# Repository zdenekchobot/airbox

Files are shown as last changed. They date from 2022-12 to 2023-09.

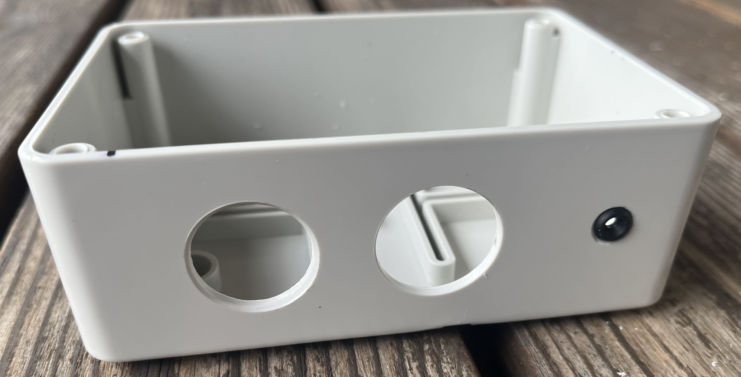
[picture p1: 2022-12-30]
Obrázky/Vyvrtaná krabička.jpg

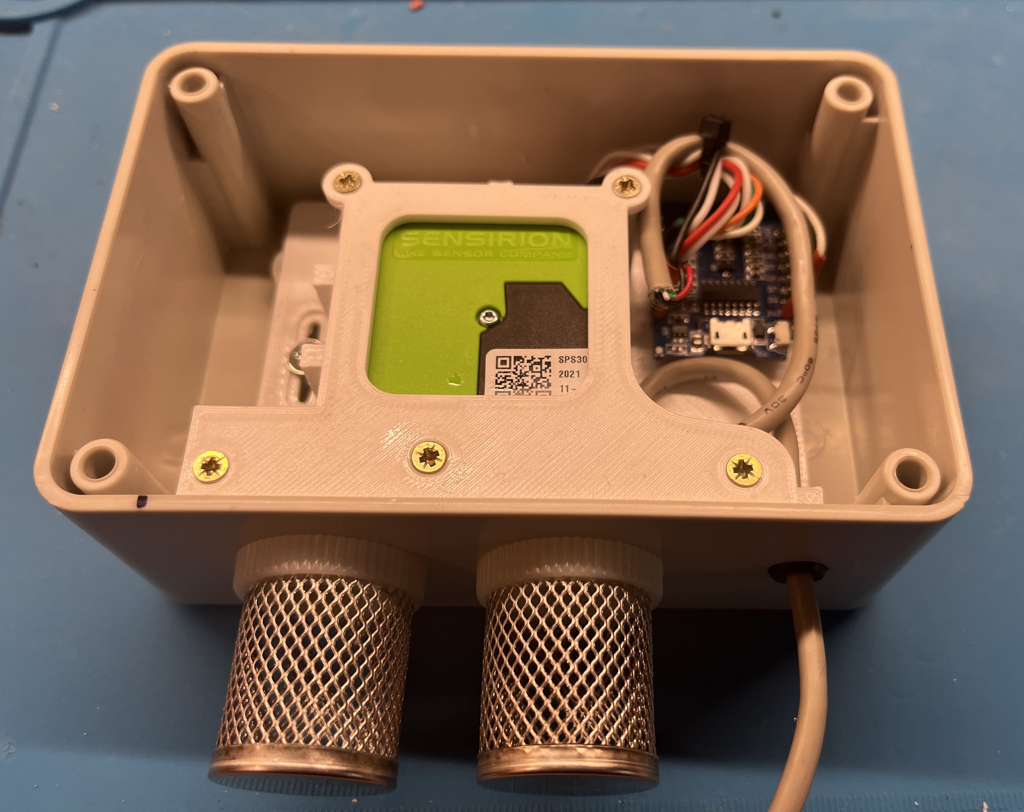
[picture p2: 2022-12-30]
Obrázky/Před zakrytováním.jpg

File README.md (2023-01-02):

# AirBox
Senzor pro měření stavu ovzduší. Pomocí dvou pokročilých senzorů měří koncentraci pevných částic PM (senzor Sensirion SPS30) a teplotu, realtivní vlkosti a tlak vzduch (senzor Bosch BME280). Jedná se variantou odvozenou ze senzorů doporučených komunitním projektem [sensor.community](https://sensor.community/cz/). Airbox používá stejné zapojení jako komunitní senzory a je tak plně kompatibilní s jejich firmware.
## Hardware
Elektronika senzoru využívá běžný modul WeMos D1 Mini s WiFi mikrokontrolerem ESP8266. Ten tvoří srdce senzoru - po sběrnici i2c komunikuje s SPS30 a BME280 a získaná data odesílá prostřednictvním internetu ke zpracování a publikaci komunitním webům, popřípadě i jinam podle vaší volby. Kvůli umístění ve venkovním prostředí je elektronika umístněna v běžné vodotěsné elektrikářské krabičce. Jednotlivé elektronické komponenty jsou upevněny na jednoduché 3D vytištěné konstrukci, která také zajišťuje vhodné proudění vzduchu. [Schéma zapojení](/Schéma/Schematic_Airbox.pdf) je jednoduché.
### Seznam komponent
- krabička [SCAME SCABOX 120x80x50mm IP56](https://www.elfetex.cz/10-078-693-scame-krabice-scabox-120x80x50mm-ip56)
- 2x [nerez sítko ke zpětné klapce DN15 - 1/2"](https://www.obchod-vtp.cz/nerez-sitko-ke-zpetne-klapce-dn15-1-2)
- [WeMos D1 Mini ESP8266 WiFi](https://dratek.cz/arduino/121932-wemos-d1-mini-esp8266-wifi-modul-v2.0.html), originál či klon
- senzor kvality ovzduší [Sensirion SPS30](https://www.soselectronic.cz/products/sensirion/sps30-2-304234)
- senzor teploty, vlhkosti a tlaku [BME280](https://dratek.cz/arduino/1361-bme280-modul-mereni-teploty-vlhkosti-a-barometrickeho-tlaku-precizni.html)
- [3D tištěné díly](/STL)
- gumová průchodka napájecího kablíku, např. [FIX-GR-98](https://www.tme.eu/cz/details/fix-gr-98/pruchodky/fix-fasten/)
- propojovací vodiče, napájecí kablík
- samosmršťovací bužírka
- kousek pěnové gumy pro fixaci a utěsnění SPS30 (samolepící je výhodou)
- samořezné šroubky
### Sestavení
Představu o sestavení senzoru poskytují [fotografie](/Obrázky) z výroby "prototypu". Poněkud nestandardní je upevnění modulu Wemos. Přiložené standardní "hřebínky" jsou **delšímí** piny nasunuty se strany ESP8266 a zapájeny. Na delší piny jsou připájeny propojovací vodče. Kratší piny jsou zasunuty do základny a dostatečně upevňují modul. Pokud potřebujete modul více fixovat, přilepte na ESP8266 oboustranně lepící (teplovodivou) pásku. Po zasunutí pinů do základny druhá strany pásky přilne k základně.      
## Software
Jako zákadní software, resp. firmware lze použít standardní, neupravený komunitní firmware. Pro jeho nahrání a konfiguraci je vhodné postupovat podle [návodu na komunitním webu](https://sensor.community/cz/sensors/airrohr/).
### Home Assistant
Do AirBoxu lze nahrát i firmware ESPHome, získaná data využít v HA a odtud je odesílat na web [sensor.community](https://sensor.community/cz/). Konfigurační soubory yaml pro ESPHome, služeb odesílání dat včetně automatizace jsou k dispozici ve [složce YAML](/YAML). 
Konfigurace služeb a automatizace je z větší části práce šikuly [hmmboba](https://github.com/hmmbob/HomeAssistantConfig) - děkuji!
## Tipy
1. Místo Wemos D1 mini doporučuji spíše modul [WeMos D1 Mini Pro 16MB](https://www.laskakit.cz/wemos-d1-mini-pro--esp8266-wifi-modul/) kvůli možnosti připojení externí antény, např. [WiFi 42x12mm anténa 2.4G 5dB](https://www.laskakit.cz/wifi-42x12mm-antena-2-4g--5db-u-fl--ipex1--konektor/) nebo [NiceRF snténa 3.0dBi 2.4G](https://www.laskakit.cz/antena-10cm-2-4g/) s příslušným pigtailem.
2. Na vrtání velkých děr do krabičky se skvěle osvědčily [stromečkové/stupňovité vrtáky](https://www.lidl.cz/p/parkside-sada-specialnich-vrtaku-psb-6-a1/p100341714004). Velké poděkování [Jiri Janovec](https://twitter.com/jjiik) a [Josef Zvolanek #ePap](https://twitter.com/JosefZvolanek) za radu!

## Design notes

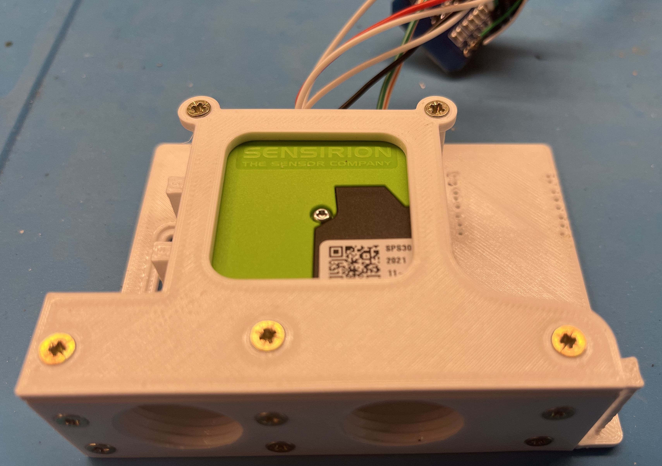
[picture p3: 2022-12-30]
Obrázky/Sešroubováno.jpg

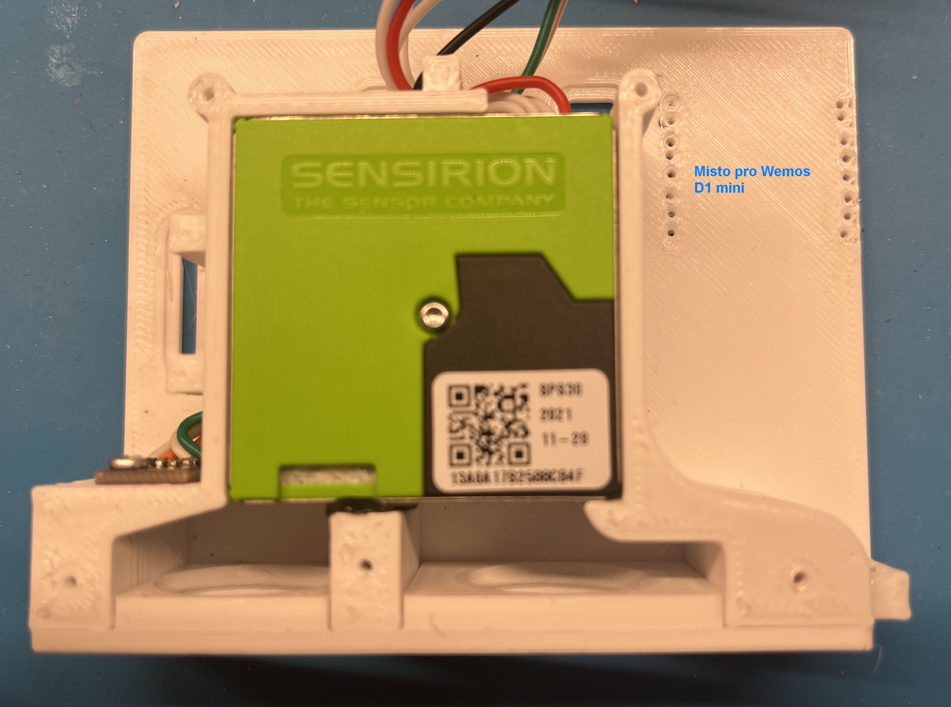
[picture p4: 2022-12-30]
Obrázky/Základna.jpg

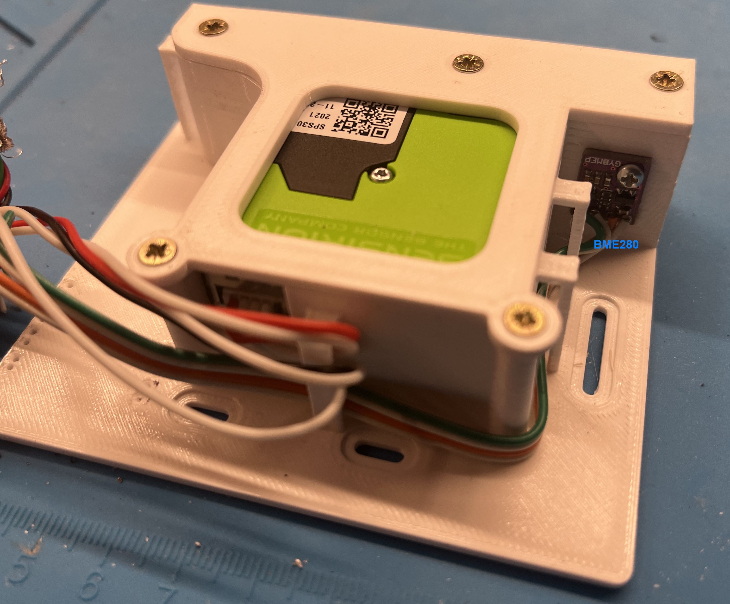
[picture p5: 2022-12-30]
Obrázky/Umístění BME280.jpg

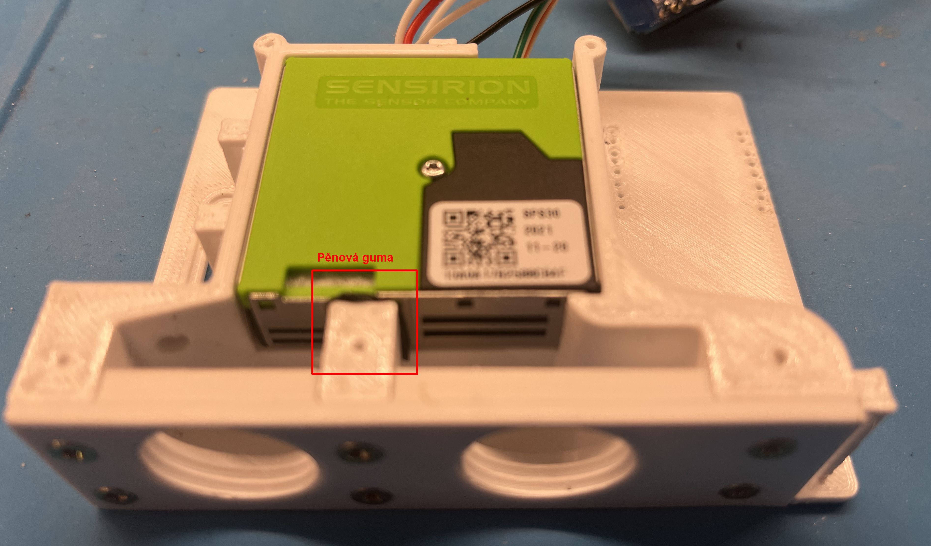
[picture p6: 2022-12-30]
Obrázky/Usazení SPS30.jpg

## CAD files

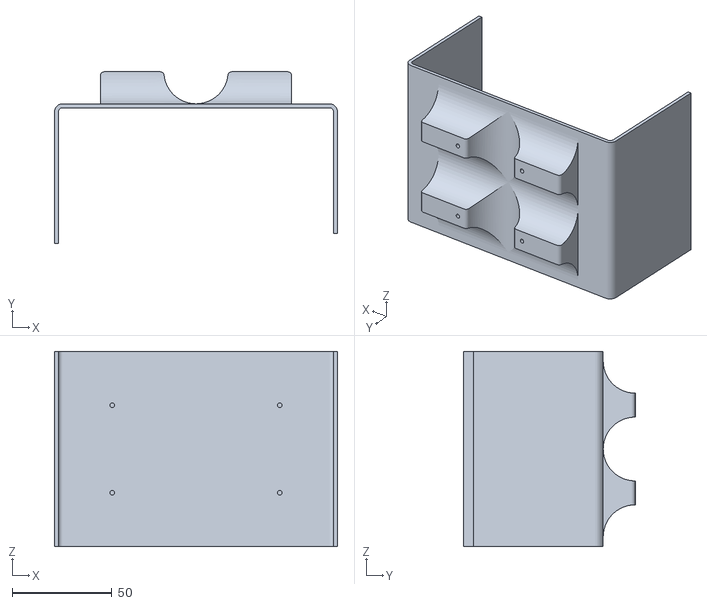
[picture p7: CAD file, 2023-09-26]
STL/AirBox-Radiační štít a držák.stl
142.0 x 86.1 x 98.0

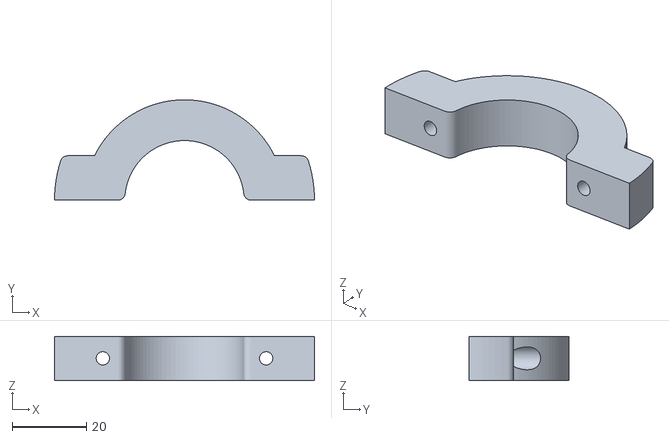
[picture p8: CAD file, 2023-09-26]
STL/AirBox-spona.stl
70.2 x 27.1 x 12.0

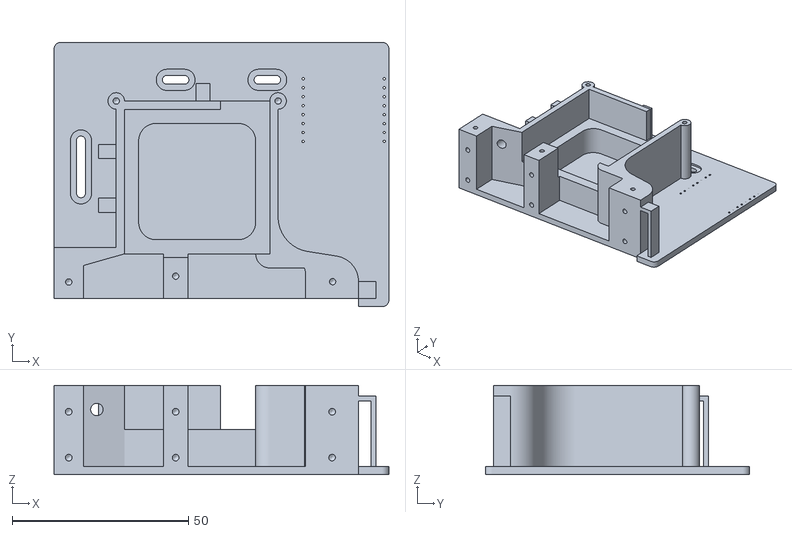
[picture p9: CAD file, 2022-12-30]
STL/AirBox-zakladna.stl
95.0 x 75.0 x 25.4

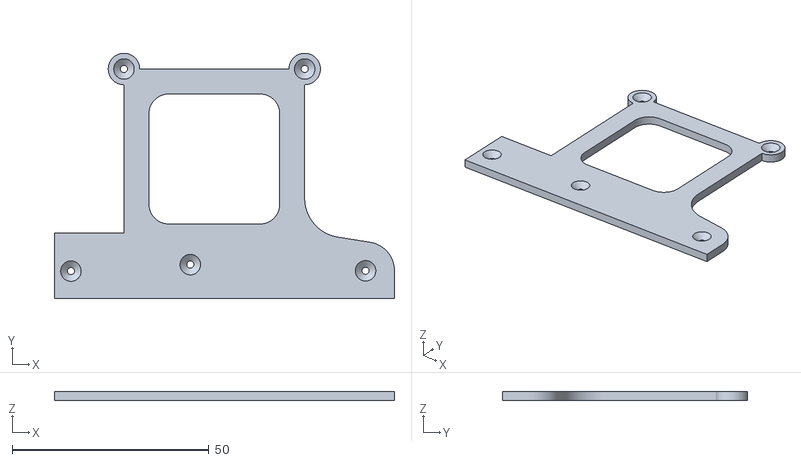
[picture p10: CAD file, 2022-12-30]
STL/AirBox-kryt.stl
86.3 x 62.3 x 2.35

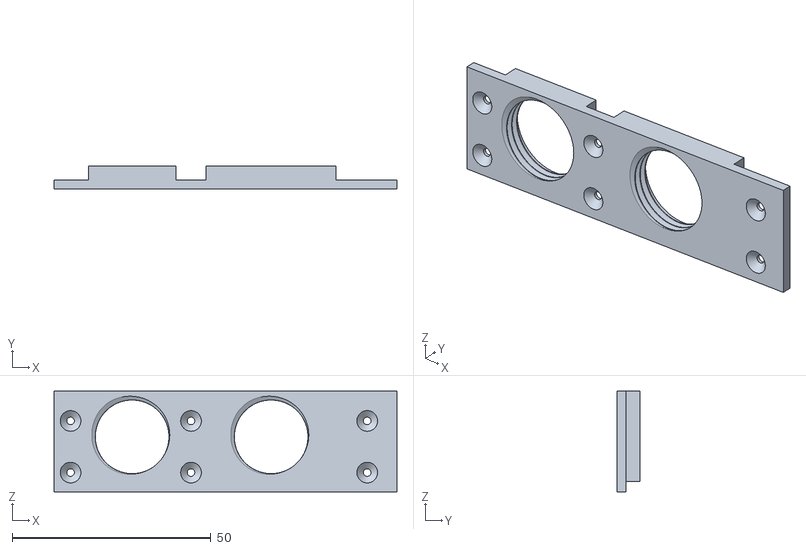
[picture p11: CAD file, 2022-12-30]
STL/AirBox-čelo.stl
86.4 x 5.85 x 25.4

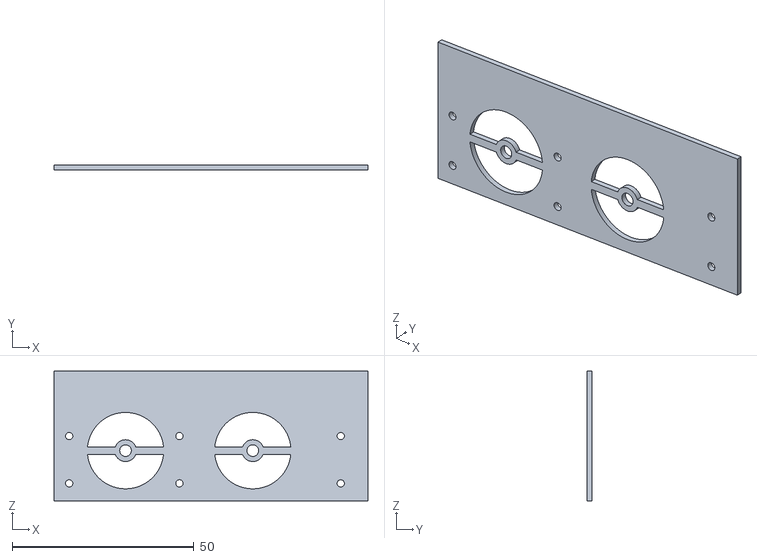
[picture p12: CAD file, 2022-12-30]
STL/AirBox-vrtací šablona.stl
86.4 x 1.35 x 35.8

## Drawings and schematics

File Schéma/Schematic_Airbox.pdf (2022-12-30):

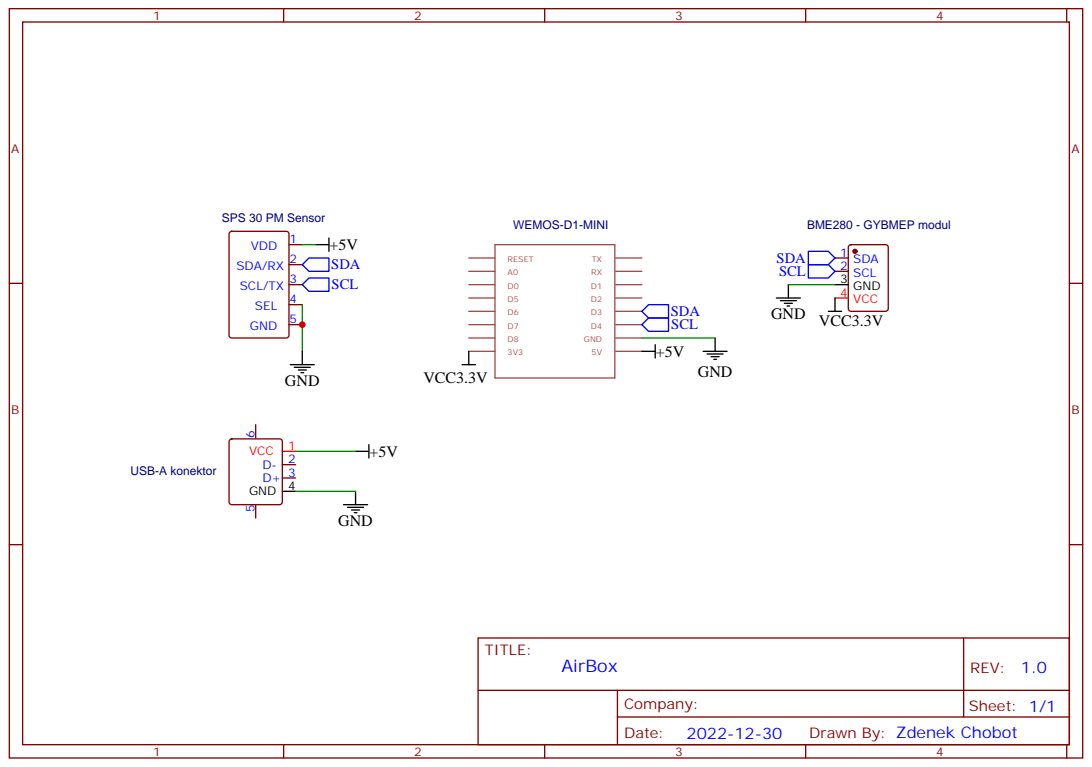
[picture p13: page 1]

Drawn By: Zdenek Chobot

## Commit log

2022-12-30 Upload STL files
    [AirBox-kryt.stl, AirBox-vrtací šablona.stl, AirBox-zakladna.stl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]
2023-09-26 Přidání radiačního krytu - držáku na trubku
    [AirBox-Radiační štít a držák.stl, AirBox-spona.stl]
2023-09-26 Web, RSSI, sea level pressure and temperature calibration added
